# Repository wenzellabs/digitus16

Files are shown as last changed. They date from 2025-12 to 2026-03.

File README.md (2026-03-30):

# digitus16

digitus16 is a 16-segment RGB display.

it comes as six digits on a single PCB. the boards can be daisy-chained for larger displays. software supports both, X and Y extensions.

comes with a 3d-printed screen as bezel and diffusor.

the single digit or whole display is controlled through a simple 2-wire SPI interface and can be hooked up to pretty much any microcontroller.

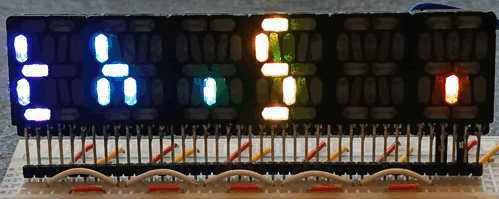
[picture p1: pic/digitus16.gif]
digitus16 in rainbow animation


# examples

see the [`software/examples/`](software/examples/) subfolder for the code

<hr>

- simple1:

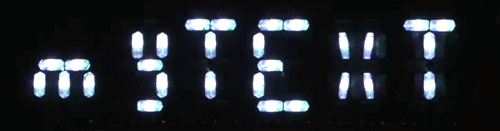
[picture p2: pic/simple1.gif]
simple1


<hr>

- simple2:

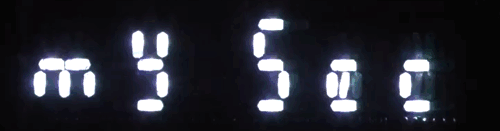
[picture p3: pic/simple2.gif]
simple2


<hr>

- simple3:

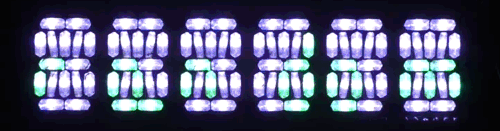
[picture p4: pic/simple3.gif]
simple3


<hr>

- simple4:

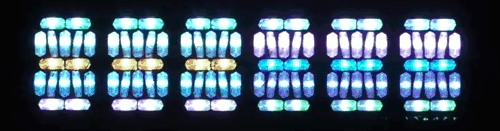
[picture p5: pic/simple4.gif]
simple4


<hr>

- simple5:

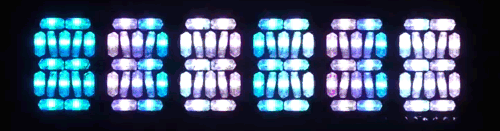
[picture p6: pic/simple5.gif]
simple5


<hr>

- seasons:

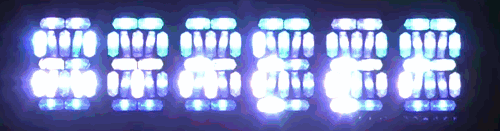
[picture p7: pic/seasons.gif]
seasons


<hr>

- temperature:

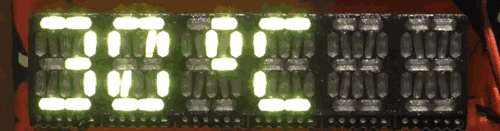
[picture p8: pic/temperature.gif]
temperature


<hr>

- demo:

demo

<hr>

# software

see the [`software/`](software/) subfolder

there is software/firmware support for
- micropython on the **ESP32** (and variants)
- micropython on the **Raspberry Pi Pico** (and variants)
- python on **linux** (Raspberry Pi and others, basically any linux with a /dev/spiX.Y)

there's software support for
- fonts
- scrolltext
- gradients
- foreground and background colors
- multicolumn multirow arrangements for larger assemblies of digits

there's planned software support for
- images using voronoi patterns (esp. for larger arrangements of digits)
- using the assembly of digits as image framebuffer

## programming

for now, just see the [`software/examples/`](software/examples/) subfolder

# hardware

## what you get
kit's content (top to bottom):

- 3d-printed bezel and diffusor

- main PCB with 6 digits of 16 SPI addressable RGB LEDs each

- 4-pin main male connector for power and SPI signals

- 4-pin main female connector for power and SPI signals

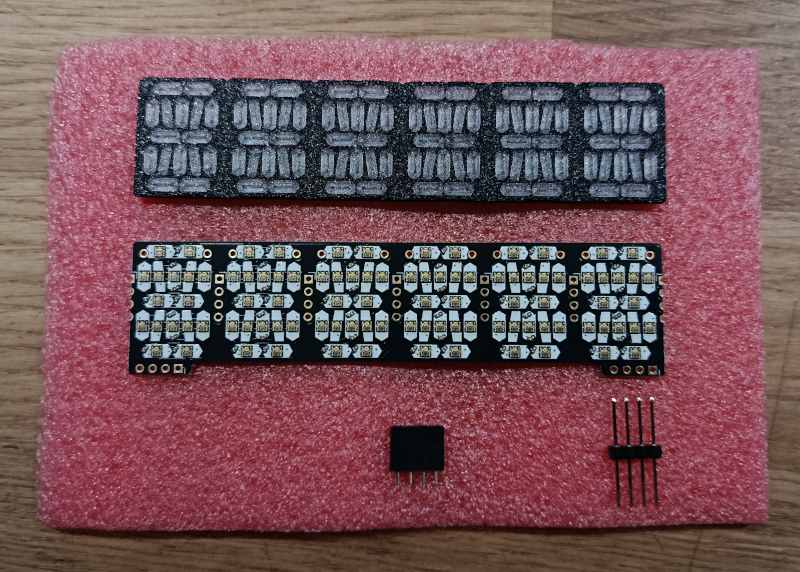
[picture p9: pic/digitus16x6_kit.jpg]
digitus16x6 kit


various assemblies are feasible. most will be a sandwich of the bare PCB and a 3d-printed bezel and diffusor. we've also successfully used bezels that were laser-cut from wood or PMMA (although PMMA becomes very brittle with the thin structures). Or paper, wood or other materials can be used as yet another diffusor and to have a uniform clean surface.

## mechanical

- display height: 26.7mm
- display height center: 24.5mm
- display width: 106.7mm
- display thickness: 5.0mm (PCB + 3d-printed bezel and diffusor)

see the [`3d/`](3d/) subfolder for 3D models.

front view:

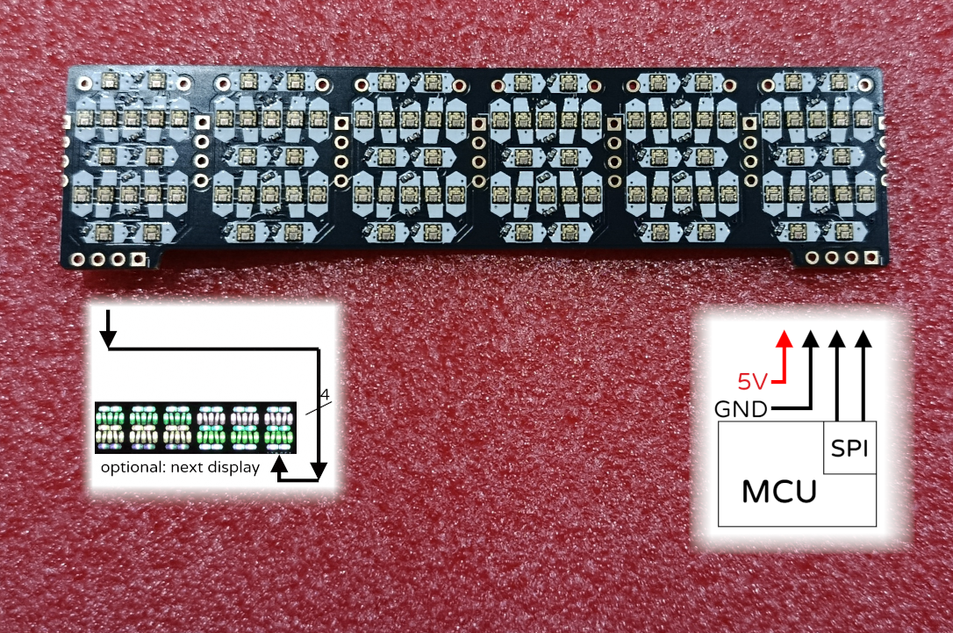
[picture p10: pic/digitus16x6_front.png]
digitus16x6 front


back view:

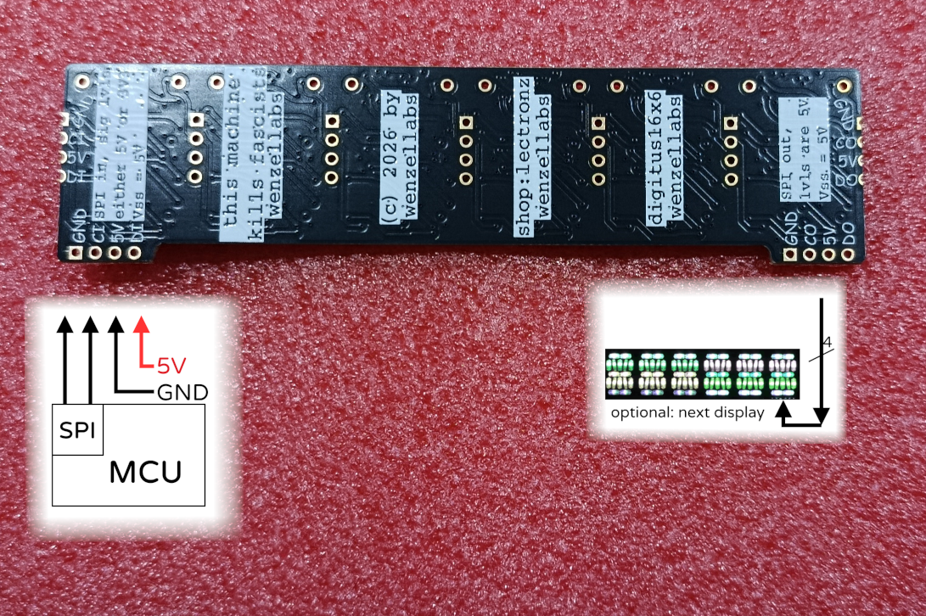
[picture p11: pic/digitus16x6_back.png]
digitus16x6 back


## electrical interface

- 5V power supply in
- GND
- SPI clock in **CI** (3.3V level or 5V level)
- SPI data in **DI** (3.3V level or 5V level)
- optional:
    - 5V power supply out
    - GND
    - SPI clock out **CO** (5V level)
    - SPI data out **DO** (5V level)

## current/power

absolute maximum current / power @5V, all LEDs 100% white, full brightness: 485mA / 2.425W

maximum current / power @5V, all LEDs 100% white, recommended maxiumum brightness (15 of 31): 280mA / 1.4W

the LEDs have a brightness setting 0-31. we recommend you only drive the LEDs up to a maxiumum brightness level of 15, otherwise you get the self-explanatory warning from the API:
```
>>> display.set_brightness(31)
setting high brightness values is not recommended due to reduced LED lifetime!
```

## assembly guide

remove the 3d-printed bezel and diffusor before soldering.

solder the four pins for the 5V and data connection to the main PCB, either vertical to the back, or flat to the bottom, according to your mounting requirements.

the pinout is documented on the backside of the PCB. see also the photo above.

only after all soldering is done snap the 3d-printed bezel and diffusor back on the main pcb. it should clip on firmly, and glueing is possible but probably not necessary.

## why SK9822/APA102 and not WS2812B flavoured RGB LEDs

we use SPI-based SK9822/APA102 and not the more widely used WS2812B flavoured RGB LEDs which require only one pin instead of two (aside from power). here are the reasons why we try to avoid WS2812B flavoured RGB LEDs whenever possible:

- WS2812B require precise timing
- WS2812B only come with an internal RC oscillator which is not very stable, especially over temperatures. there's no way to accurately drive WS2812B over wide temperature ranges
- WS2812B require bitbanging. the timing has to be granted in SW/FW since there's no special WS2812B HW unit on MCUs
- to keep the timing all other interrupts must be disabled on the MCU
- disabling interrupts can mean loosing other events on the MCU, e.g. you start loosing button presses or keystrokes on the UART
- SK9822s or APA102s come with an extra line, that is clock, the advantage is that the SW/FW can run them fast or slow or even pause the transmission, e.g. during high prio interrupts
- most MCUs have a dedicated SPI master controler HW integrated, that means no bitbanging from SW
- if you have an RTOS like FreeRTOS the RGB LED task doesn't need the highest priority/disable the interrupts anymore, and you won't miss CAN-frames while you render that mmeeoww on the screen

end-of-WS2812B-rant

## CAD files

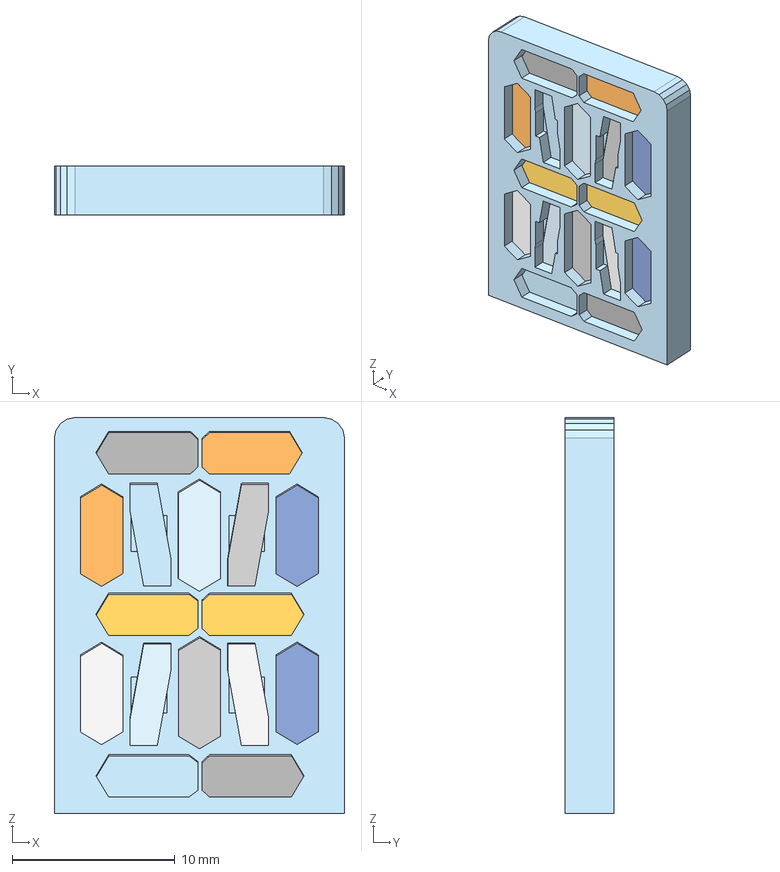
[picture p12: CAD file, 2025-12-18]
3d/digitus16screen1.step
17.8 x 3.00 x 24.3 mm

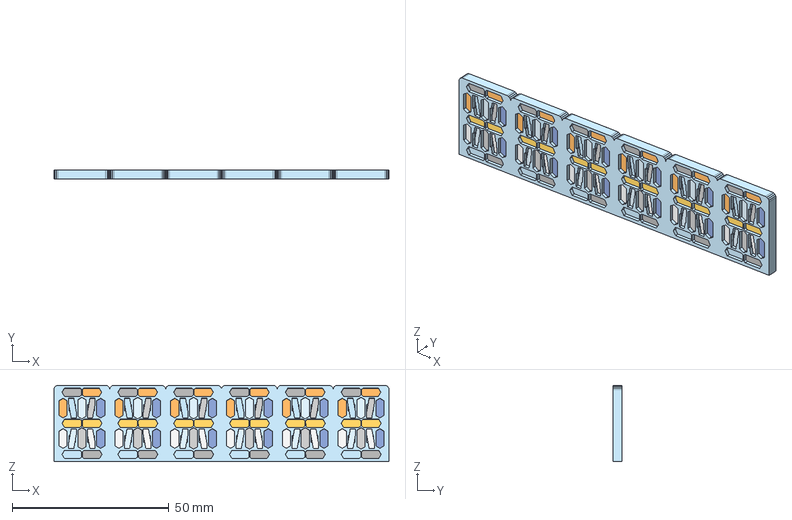
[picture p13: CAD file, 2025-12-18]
3d/digitus16screen6.step
106.9 x 3.00 x 24.3 mm

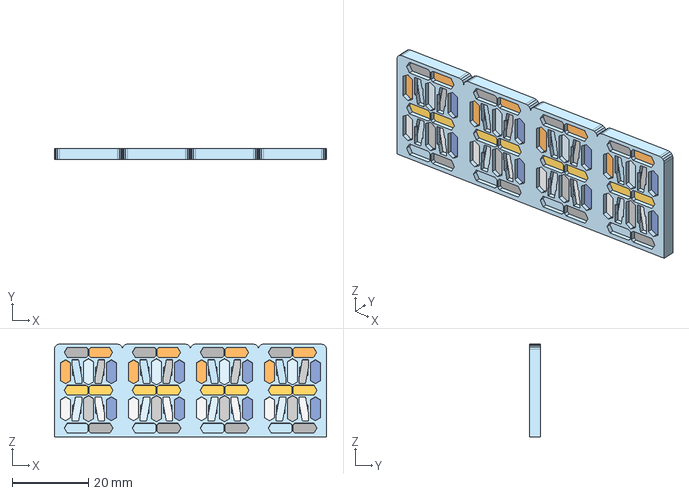
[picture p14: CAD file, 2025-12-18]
3d/digitus16screen4.step
71.3 x 3.00 x 24.3 mm

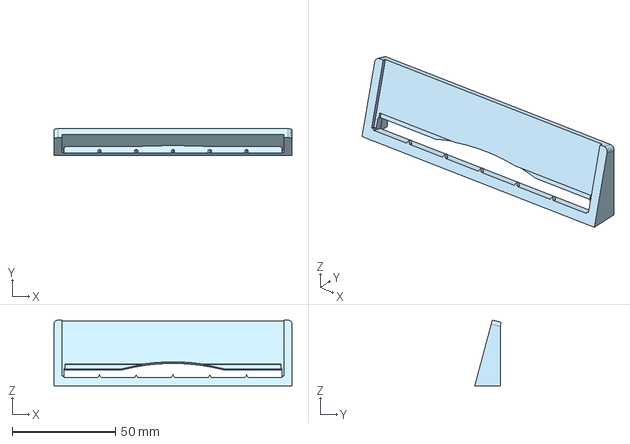
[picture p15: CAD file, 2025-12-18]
3d/digitus16stand6.step
115.0 x 12.9 x 31.9 mm

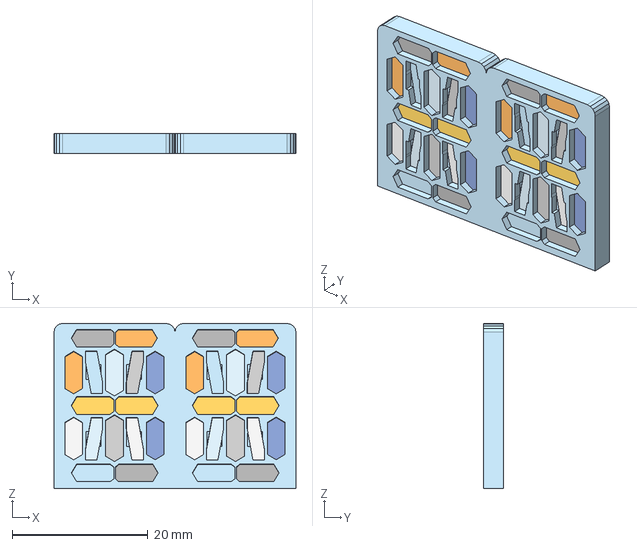
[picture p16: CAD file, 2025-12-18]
3d/digitus16screen2.step
35.6 x 3.00 x 24.3 mm

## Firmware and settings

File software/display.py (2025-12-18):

from digit import Digit
import sys

class Layer:
    FG = "foreground"
    BG = "background"

class Display:
    def __init__(self):

        self.elements = []
        self.digits = []
        self.ordered_leds = []
        self.digit_count = 0

        self.x_display = 0
        self.y_display = 0
        self.x_items = 0
        self.y_items = 0
        self.x_cursor = 0
        self.y_cursor = 0

        self.mode = 'alphanum'  # or 'raw'

        self.text = ''
        self.text_anim_direction = 'left'  # or 'right'
        self.text_render_index = 0

        self.brightness = 2 # 0 (off) to 31

        # SPI configuration (default values, will be set per platform)
        self.spi_baudrate = 4000000
        plat = sys.platform
        if plat == "rp2":
            # Pi Pico: GP2=SCK, GP3=MOSI
            self.spi_n = 0
            self.spi_sck = 2
            self.spi_mosi = 3
        elif plat == "esp32":
            # ESP32: D8=SCK, D10=MOSI (user specified)
            # On ESP32, pins are usually specified by GPIO number, e.g. D8=8, D10=10
            self.spi_n = 1
            self.spi_sck = 4
            self.spi_mosi = 6
        elif plat.startswith("linux"):
            # Linux systems (including Raspberry Pi): use spidev
            self.spi_bus = 0  # Default SPI bus number
            self.spi_device = 0  # Default SPI device number
            self.set_linux_spi_dev_path(f"/dev/spidev{self.spi_bus}.{self.spi_device}")
        else:
            print(f"Unsupported platform '{sys.platform}' for SPI pin mapping")

    def set_spi(self, n: int):
        self.spi_n = n

    def set_sck(self, pin: int):
        self.spi_sck = pin

    def set_mosi(self, pin: int):
        self.spi_mosi = pin

    def set_spi_baudrate(self, baudrate: int):
        self.spi_baudrate = baudrate

    def set_linux_spi_dev_path(self, path: str):
        self.spi_dev_path = path

    def extend(self, LED_obj, direction='horizontal'):
        self.elements.append(LED_obj)
        if isinstance(LED_obj, Digit):
            self.digit_count += 1
            self.digits.append(LED_obj)

        self.ordered_leds += LED_obj.get_leds()

        if direction == 'horizontal':
            if self.x_cursor == 0 and self.y_cursor == 0: # first entry
                self.x_items += 1
                self.y_items += 1
                self.x_cursor += 1
                self.y_cursor += 1
                self.x_display += LED_obj.get_width()
                self.y_display += LED_obj.get_height()
            else:
                if self.x_cursor >= self.x_items: # are we widening?
                    self.x_cursor += 1
                    self.x_items += 1
                    self.x_display += LED_obj.get_width()
                else:
                    self.x_cursor += 1
            if isinstance(LED_obj, Digit):
                LED_obj.extend_horiz(self.x_cursor-1)
        elif direction == 'vertical':
            if self.x_cursor == 0 and self.y_cursor == 0: # first entry
                self.x_items += 1
                self.y_items += 1
                self.x_cursor += 1
                self.y_cursor += 1
                self.x_display += LED_obj.get_width()
                self.y_display += LED_obj.get_height()
            else:
                if self.y_cursor >= self.y_items: # are we raising?
                    self.y_cursor += 1
                    self.y_items += 1
                    self.y_display += LED_obj.get_height()
                else:
                    self.y_cursor += 1
            if isinstance(LED_obj, Digit):
                LED_obj.extend_vert(self.y_cursor-1)

    def get_cursor(self):
        return self.x_cursor, self.y_cursor

    def set_cursor(self, x: int, y: int):
        self.x_cursor = x
        self.y_cursor = y

    def get_dimensions(self):
        return self.x_display, self.y_display

    def get_int_dimensions(self):
        return self.x_items, self.y_items

    def get_aspect_ratio(self):
        return self.x_display / self.y_display if self.y_display != 0 else 0

    def turn_digit_on(self, n):
        if 0 <= n < self.digit_count:
            self.digits[n].turn_on()

    def turn_digit_off(self, n):
        if 0 <= n < self.digit_count:
            self.digits[n].turn_off()

    def turn_all_digits_off(self):
        for digit in self.digits:
            digit.turn_off()

    def turn_all_digits_on(self):
        for digit in self.digits:
            digit.turn_on()

    def set_mode(self, mode):
        assert mode in ['alphanum', 'raw']
        self.mode = mode

    def get_state(self):
        return {
            'mode': self.mode,
            'digits': [digit.get_state() for digit in self.digits],
        }

    def set_text(self, text, direction='left'):
        self.text = text
        self.text_anim_direction = direction
        self.text_render_index = 0

    def set_number(self, number, direction='left'):
        num_str = str(number)
        # Right-align by adding leading spaces if needed
        if len(num_str) < self.digit_count:
            num_str = ' ' * (self.digit_count - len(num_str)) + num_str
        self.set_text(num_str, direction)

    def text_advance(self, bounce=True):
        """
        Advance the text scroll position.
        If bounce is True, text bounces at ends (back and forth).
        If bounce is False, text scrolls left and repeats from the start.
        """
        max_index = max(0, len(self.text) - self.digit_count)
        pause_ticks = 3
        if not hasattr(self, '_pause_counter'):
            self._pause_counter = 0
        if bounce:
            if self.text_anim_direction == 'left':
                if self.text_render_index < max_index:
                    self.text_render_index += 1
                    self._pause_counter = 0
                else:
                    if self._pause_counter < pause_ticks:
                        self._pause_counter += 1
                    else:
                        self.text_anim_direction = 'right'
                        self._pause_counter = 0
            elif self.text_anim_direction == 'right':
                if self.text_render_index > 0:
                    self.text_render_index -= 1
                    self._pause_counter = 0
                else:
                    if self._pause_counter < pause_ticks:
                        self._pause_counter += 1
                    else:
                        self.text_anim_direction = 'left'
                        self._pause_counter = 0
        else:
            # Only scroll left, repeat from start
            if self.text_render_index < max_index:
                self.text_render_index += 1
            else:
                self.text_render_index = 0
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

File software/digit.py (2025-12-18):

from led_strip import LED_strip

# 16-segment naming:
#
#  a a a b b b
# h k   m   n c
# h  k  m  n  c
# h   k m n   c
#  u u u p p p
# g   t s r   d
# g  t  s  r  d
# g t   s   r d
#  f f f e e e

# wiring order in digitus16 HW: E-F-D-R-S-T-G-P-U-C-N-M-K-H-B-A
#
SEGMENT_16_ORDER = [
    'e', 'f',
    'd', 'r', 's', 't', 'g',
    'p', 'u',
    'c', 'n', 'm', 'k', 'h',
    'b', 'a'
]

# digitus16 is 17.78mm x 27.94mm
x_digitus16 = 17.78
y_digitus16 = 27.94
aspect_ratio_digitus16 = 17.78 / 27.94

DIGITUS16_COORDS = {
    'a': [  5.8125, 25.78 ], # /17.78, /27.94
    'b': [ 11.8125, 25.78 ], # /17.78, /27.94
    'c': [ 14.8125, 20.82 ], # /17.78, /27.94
    'd': [ 14.8125, 10.90 ], # /17.78, /27.94
    'e': [ 11.8125,  5.94 ], # /17.78, /27.94
    'f': [  5.8125,  5.94 ], # /17.78, /27.94
    'g': [  2.8125, 10.90 ], # /17.78, /27.94
    'h': [  2.8125, 20.82 ], # /17.78, /27.94
    'k': [  5.8125, 20.82 ], # /17.78, /27.94
    'm': [  8.8125, 20.82 ], # /17.78, /27.94
    'n': [ 11.8125, 20.82 ], # /17.78, /27.94
    'p': [ 11.8125, 15.86 ], # /17.78, /27.94
    'r': [ 11.8125, 10.90 ], # /17.78, /27.94
    's': [  8.8125, 10.90 ], # /17.78, /27.94
    't': [  5.8125, 10.90 ], # /17.78, /27.94
    'u': [  5.8125, 15.86 ], # /17.78, /27.94
}

# Logical/alphabetical order for font bits:
SEGMENT_16_FONT_ORDER = [
    'a', 'b', 'c', 'd', 'e', 'f', 'g', 'h',
    'k', 'm', 'n', 'p', 'r', 's', 't', 'u'
]

# font definition for 16-segment display
FONT_16SEG_RAW = [
    (" ", 0b0000000000000000),
    ("!", 0b0000000000001100),
    ('"', 0b0000001000000100),
    ('#', 0b1010101000111100),
    ('$', 0b1010101010111011),
    ('%', 0b1110111010011001),
    ('&', 0b1001001101110001),
    ("'", 0b0000001000000000),
    ('(', 0b0001010000000000),
    (')', 0b0100000100000000),
    ('*', 0b1111111100000000),
    ('+', 0b1010101000000000),
    (',', 0b0100000000000000),
    ('-', 0b1000100000000000),
    ('.', 0b0000000000100000),
    ('/', 0b0100010000000000),
    ('0', 0b0100010011111111),
    ('1', 0b0000010000001100),
    ('2', 0b1000100001110111),
    ('3', 0b0000100000111111),
    ('4', 0b1000100010001100),
    ('5', 0b1001000010110011),
    ('6', 0b1000100011111011),
    ('7', 0b0000000000001111),
    ('8', 0b1000100011111111),
    ('9', 0b1000100010111111),
    (':', 0b0010001000000000),
    (';', 0b0100001000000000),
    ('<', 0b1001010000000000),
    ('=', 0b1000100000110000),
    ('>', 0b0100100100000000),
    ('?', 0b0010100000000111),
    ('@', 0b0000101011110111),
    ('A', 0b1000100011001111),
    ('B', 0b0010101000111111),
    ('C', 0b0000000011110011),
    ('D', 0b0010001000111111),
    ('E', 0b1000000011110011),
    ('F', 0b1000000011000011),
    ('G', 0b0000100011111011),
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
    ('\xff', 0b1111111111111111),
]

# Build font mapping:
FONT_16SEG = {}
for char, bits in FONT_16SEG_RAW:
    FONT_16SEG[char] = [seg for i, seg in enumerate(SEGMENT_16_FONT_ORDER) if (bits >> i) & 1]

class Digit(LED_strip):
    def __init__(self, index=0):
        super().__init__(count=16)
        self.index = index
        for i, seg_name in enumerate(SEGMENT_16_ORDER):
            coords = DIGITUS16_COORDS.get(seg_name, [0.0, 0.0])
            self.LEDs[i].set_x(coords[0])
            self.LEDs[i].set_y(coords[1])
        self.width = x_digitus16
        self.height = y_digitus16

    def get_width(self):
        return self.width

    def extend_horiz(self, hops: int):
        for l in self.LEDs:
            l.set_x(l.get_x() + x_digitus16*hops)

    def get_height(self):
        return self.height

    def extend_vert(self, hops: int):
        for l in self.LEDs:
            l.set_y(l.get_y() + y_digitus16*hops)

    def turn_on(self):
        for l in self.LEDs:
            l.turn_on()

    def turn_off(self):
        for l in self.LEDs:
            l.turn_off()

    def set_fg(self, color):
        for l in self.LEDs:
            l.set_fg(color)

    def set_bg(self, color):
        for l in self.LEDs:
            l.set_bg(color)

    def set_char(self, ch):
        # Turn off all LEDs first
        for l in self.LEDs:
            l.turn_off()
        lit = FONT_16SEG.get(ch)
        if not lit:
            return
        for seg_name in lit:
            if seg_name in SEGMENT_16_ORDER:
                seg_index = SEGMENT_16_ORDER.index(seg_name)
                self.LEDs[seg_index].turn_on()

    def get_color(self):
        digit_color = {l.get_color() for l in self.LEDs}
        return digit_color

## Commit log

2025-12-18 add all pics, sw, and 3d files
    [digitus16screen1.step, digitus16screen2.step, digitus16screen4.step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]
2025-12-18 link the digitus16 kit assembly guide
2026-01-04 add software/examples/W20.py - a basic W20 die
2026-01-04 software/examples/W20.py idle demo has temperature too
2026-01-25 blonkenclick: don't show battery level anymore, it's incorrect anyway with USB supply
2026-03-30 there's no more single, dual or quad boards
